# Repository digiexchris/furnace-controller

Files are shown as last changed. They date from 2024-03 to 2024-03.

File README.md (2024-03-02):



# furnace-controller
Simple 5 wire furnace controller using the Lotlin S2 Mini. Intended for ESPHome and Home Assistant or other automation uses.

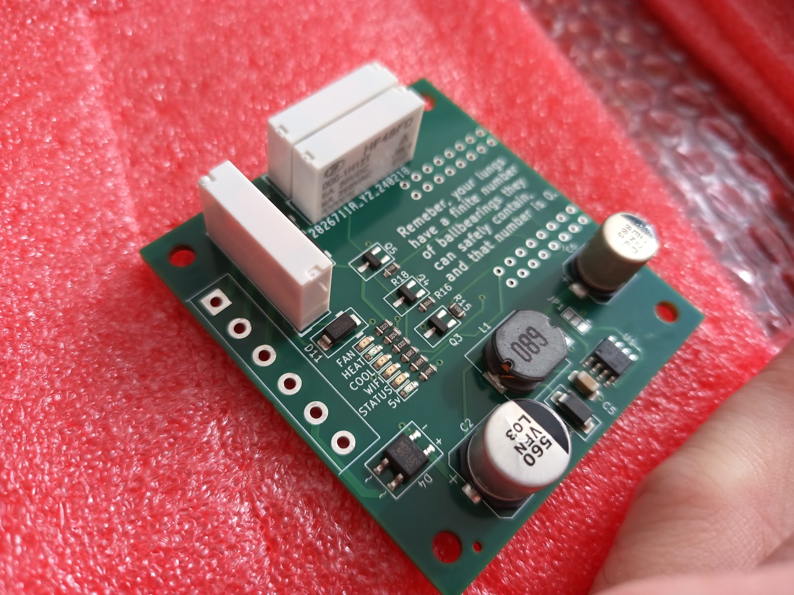
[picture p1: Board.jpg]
Board

Back
Running

# Why this exists
It's difficult to find a power supply to run an esp32 or esp8266 (or any 5vdc device for that matter) off of the 24vac transformer typically used in a furnace. This is intended to provide power and 3 relays connected to an esp8266 so that it can run anywhere that the thermostat wires are run in your house (or, as in my case, mounted directly to the furnace cabinet).

# Deets
- Accepts AC or DC input power, up to about 30V maximum. It's possible that it will accept up to 42v, but I have not tested it at that level, and you very likely will let the smoke out. Check the specs on the DC-DC IC for more info.
- 5A Relays, up to 30VDC or 250VAC contacts. 
- Avoids most of the multipurpose pins on the lotlin S2 mini, so you can use them for something else.
- Provides das blinken lighten for telling you if the furnace should be on

# Pinout

| Function | Esp32-S2 Pin |
|---|---|
| Heat | IO35 |
| Cool | IO18 |
| Fan | IO33 |
| WIFI Led | IO09 |
| Status LED | IO05 |

# I WANT ONE!

You have a few options:
- whack together one using whatever you have on hand using the schematic (see the kicad project, Kicad 8.0 btw.)
- Shoot me an email at chris@voiditswarranty.com, or see VoidItsWarranty.com, and ask me to make one for you
- Have a board house like jlcpcb make you one. The kicad folder contains the production files used for my first few.

# Example ESPHome config

See furnace-controller.yaml in the root of this project for an example ESPHome config. Once it's up and running in ESPHome, you can use it as a normal set of switches for your thermostat, or any other automation that the relays can support.

# FAQ
- Q: The LEDs are too bright! A: yup, sorry about that
- Q: Will it work on my furnace? A: no idea. Probably, if it's a standard 3-5 wire thermostat and the control circuitry is 24VAC.
- Q: I don't like it. A: Neither does my carpal tunnel.

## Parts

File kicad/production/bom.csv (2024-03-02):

Designator | Footprint | Quantity | Value | LCSC Part #
C2 | CP_Elec_10x10.5 | 1 | 470uf 35v
C5 | 1206 | 1 | 1uf 50v
C6 | CP_Elec_8x10.5 | 1 | 180uf 20v
D1 | 0603 | 1 | 5v | C2286
D10 | 0603 | 1 | COOL | C72038
D11, D12, D13, D15 | D_SMA | 4 | SS14 | C2480
D14 | 0603 | 1 | WIFI | C72038
D2 | 0603 | 1 | FAN | C72038
D3 | 0603 | 1 | HEAT | C2286
D4 | Diode_Bridge_MBS | 1 | MB10S | C2488
D5 | 0603 | 1 | STATUS | C72038
H1, H2, H3, H4 | MountingHole_3.5mm | 4 | MountingHole
J1 | TerminalBlock_bornier-6_P5.08mm | 1 | Screw_Terminal_01x06 | C5188023
JP1 | SolderJumper-3_P1.3mm_Bridged2Bar12_Pad1.0x1.5mm | 1 | Jumper_2_Bridged
JP2 | SolderJumper-2_P1.3mm_Bridged_Pad1.0x1.5mm | 1 | Jumper_2_Bridged
K1, K2, K5 | Relay_SPST_TE_PCN-1xxD3MHZ | 3 | UMS05-1A80-75L | C28975
L1 | L_10.4x10.4_H4.8 | 1 | 68uh 2a
Q3, Q4, Q5 | SOT-23_BigPads | 3 | MMBT3904 | C20526
R13 | 0603 | 1 | 2k | C17437
R14 | 0603 | 1 | 2k | C17408
R15, R16, R18 | 0603 | 3 | 470 | C17710
R17 | 0603 | 1 | 2k | C17471
R19, R21 | 0603 | 2 | 1k | C17720
R2k1 | 0603 | 1 | 1k | C17415
U1 | SOIC-8-1EP_3.9x4.9mm_P1.27mm_EP2.41x3.81mm | 1 | XL1509-5.0
U2 | ESP32_lotlin_mini | 1 | mini_esp32

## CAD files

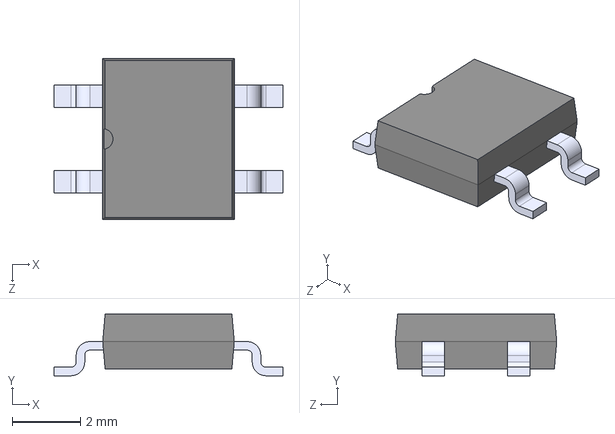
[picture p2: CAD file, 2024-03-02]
kicad/footprints/mb10f/MB10F-13.step
6.70 x 1.80 x 4.72 mm

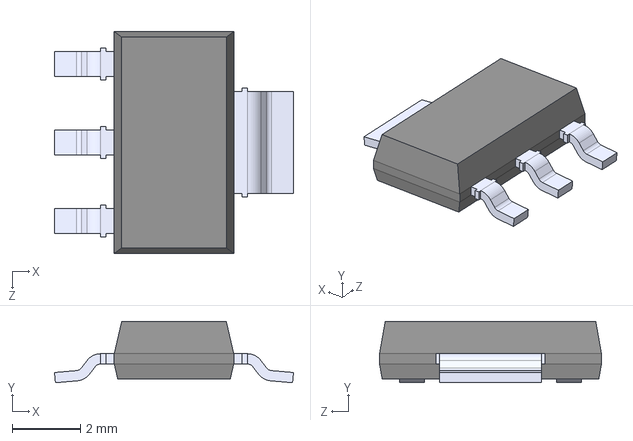
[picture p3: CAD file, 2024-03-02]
kicad/footprints/ncp1117/NCP1117STAT3.step
7.00 x 1.80 x 6.50 mm

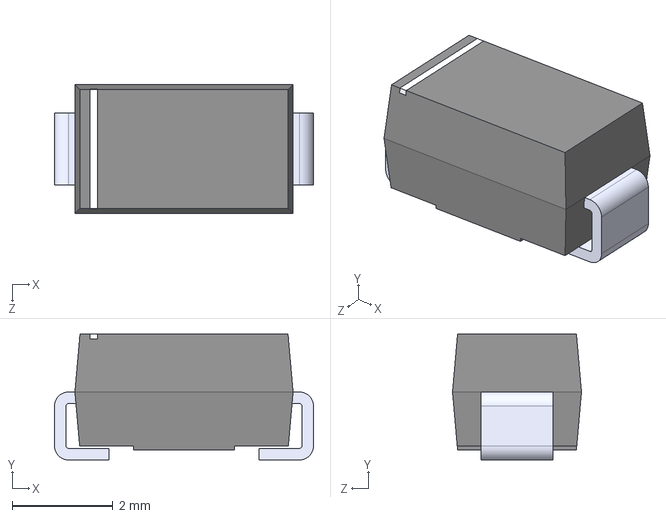
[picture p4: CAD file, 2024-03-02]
kicad/footprints/ss14/SS14.step
5.14 x 2.50 x 2.56 mm

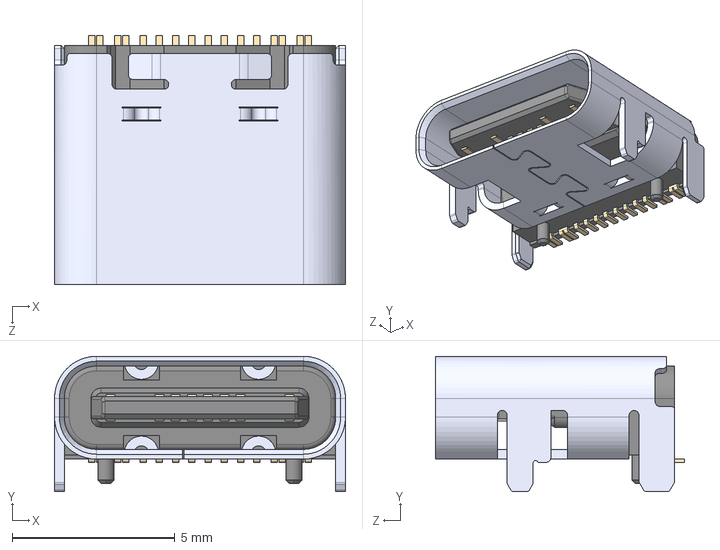
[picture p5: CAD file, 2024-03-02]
kicad/footprints/usb-c/TYPE-C_16PIN_2MD__073_.step
8.94 x 4.16 x 7.65 mm

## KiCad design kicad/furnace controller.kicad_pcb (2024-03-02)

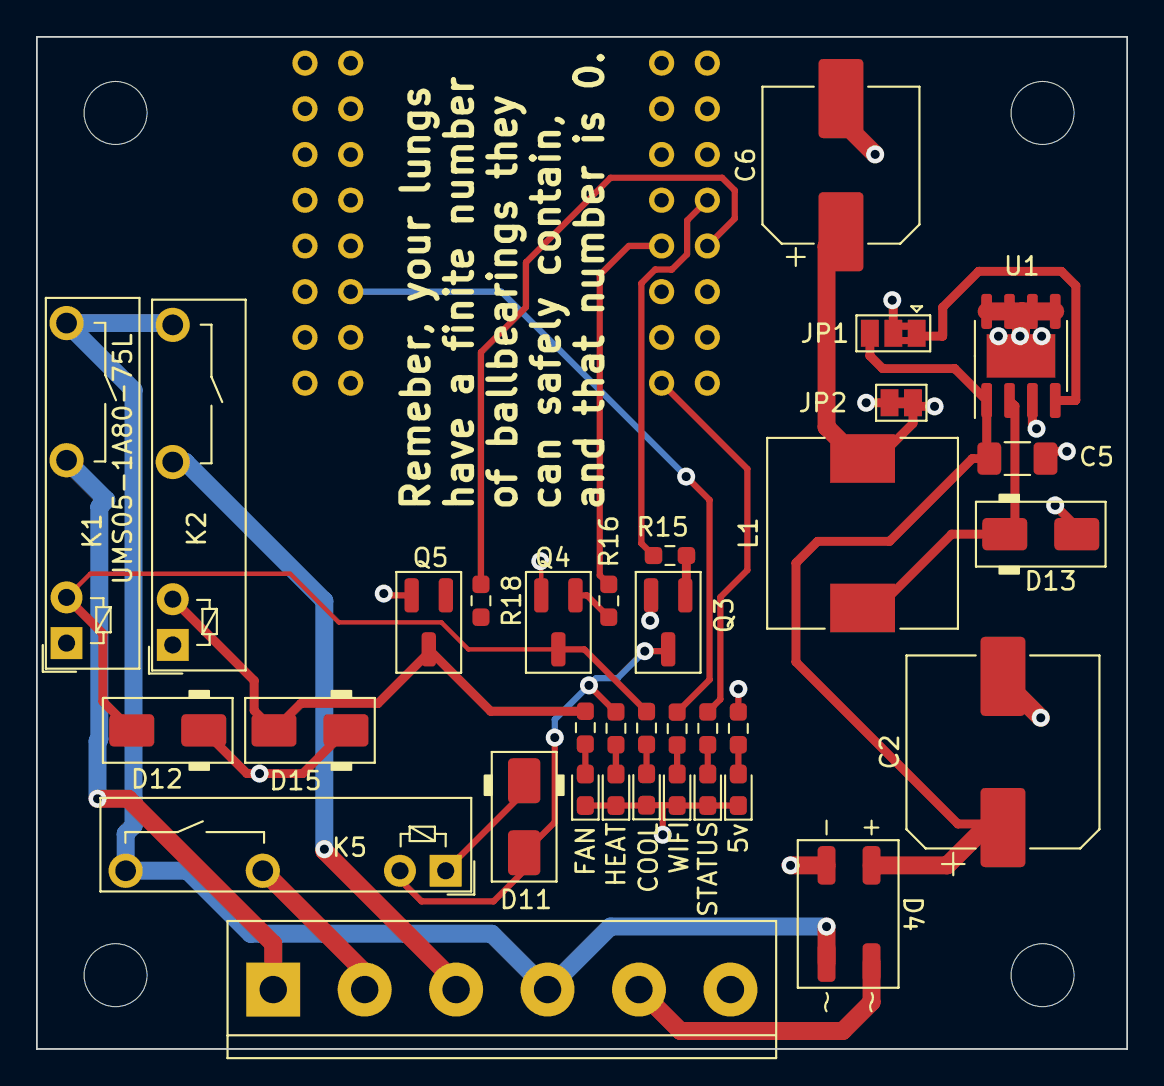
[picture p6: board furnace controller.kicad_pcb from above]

Board: 4 copper layers, 60.6 x 56.2 mm, 39 parts (1 on the bottom side), 28 nets.

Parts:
C2: 470uf 35v; CP_Elec_10x10.5
C5: 1uf 50v; C_1206_3216Metric_Pad1.33x1.80mm_HandSolder
C6: 180uf 20v; CP_Elec_8x10.5
D1: 5v; LED_0603_1608Metric_Pad1.05x0.95mm_HandSolder
D2: FAN; LED_0603_1608Metric_Pad1.05x0.95mm_HandSolder
D3: HEAT; LED_0603_1608Metric_Pad1.05x0.95mm_HandSolder
D4: MB10S; Diode_Bridge_MBS
D5: STATUS; LED_0603_1608Metric_Pad1.05x0.95mm_HandSolder
D10: COOL; LED_0603_1608Metric_Pad1.05x0.95mm_HandSolder
D11, D12, D13, D15: SS14; D_SMA
D14: WIFI; LED_0603_1608Metric_Pad1.05x0.95mm_HandSolder
H1, H2, H3, H4: MountingHole; MountingHole_3.5mm
J1: Screw_Terminal_01x06; TerminalBlock_bornier-6_P5.08mm
JP1: Jumper_2_Bridged; SolderJumper-3_P1.3mm_Bridged2Bar12_Pad1.0x1.5mm
JP2: Jumper_2_Bridged; SolderJumper-2_P1.3mm_Bridged_Pad1.0x1.5mm
K1, K2, K5: UMS05-1A80-75L; Relay_SPST_TE_PCN-1xxD3MHZ
L1: 68uh 2a; L_10.4x10.4_H4.8
Q3, Q4, Q5: MMBT3904; SOT-23_BigPads
R2k1, R19, R21: 1k; R_0603_1608Metric_Pad0.98x0.95mm_HandSolder
R13, R14, R17: 2k; R_0603_1608Metric_Pad0.98x0.95mm_HandSolder
R15, R16, R18: 470; R_0603_1608Metric_Pad0.98x0.95mm_HandSolder
U1: XL1509-5.0; SOIC-8-1EP_3.9x4.9mm_P1.27mm_EP2.41x3.81mm
U2: mini_esp32; ESP32_lotlin_mini

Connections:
+5V: D11.1 (K), D12.1 (K), D15.1 (K), JP2.2 (B), K1.1, K2.1, K5.1, R19.2, U2.35 (VCC_(USB)), U2.VBUS
/MCU/COOL: R16.1, U2.8 (IO_18/D5)
/MCU/FAN: R18.1, U2.9 (IO_33)
/MCU/HEAT: R15.1, U2.7 (IO_35)
/Power Supply/C: D4.4 (2), J1.5 (C)
/Relays/COOLLED: D12.2 (A), K1.2, Q4.3 (C), R14.2
/Relays/FANLED: D15.2 (A), K2.2, Q5.3 (C), R13.2
/Relays/G: J1.3 (G), K2.3
/Relays/HEATLED: D11.2 (A), K5.2, Q3.3 (C), R17.2
/Relays/W: J1.2 (W), K5.3
/Relays/Y: J1.1 (Y), K1.3
GND: C2.2, C5.2, C6.2, D1.1 (K), D2.1 (K), D3.1 (K), D4.2 (-), D5.1 (K), D10.1 (K), D13.2 (A), D14.1 (K), JP1.2 (C), Q3.2 (E), Q4.2 (E), Q5.2 (E), U1.5 (GND), U1.6 (GND), U1.7 (GND), U1.8 (GND), U1.9 (GND), U2.33 (GND), U2.GND
LINE: D4.3 (1), J1.4 (R), K1.4, K2.4, K5.4
unnamed: D1.2 (A), R19.1
unnamed: D2.2 (A), R13.1
unnamed: D3.2 (A), R17.1
unnamed: C2.1, C5.1, D4.1 (+), JP1.3 (B), U1.1 (VIN)
unnamed: D5.2 (A), R21.1
unnamed: D10.2 (A), R14.1
unnamed: D13.1 (K), L1.1, U1.2 (OUT)
unnamed: D14.2 (A), R2k1.1
unnamed: JP1.1 (A), U1.4 (~EN)
unnamed: C6.1, JP2.1 (A), L1.2, U1.3 (FB)
unnamed: Q3.1 (B), R15.2
unnamed: Q4.1 (B), R16.2
unnamed: Q5.1 (B), R18.2
unnamed: R21.2, U2.14 (IO_05/D8)
unnamed: R2k1.2, U2.17 (IO_09/SD2)

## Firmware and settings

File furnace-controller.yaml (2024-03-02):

esphome:
  name: furnace-controller

esp32:
  board: lolin_s2_mini

# Enable logging
logger:

switch:
  - platform: gpio
    pin: 8
    name: "Furnace Cool"
    id: relay1
    interlock: [relay2]
    restore_mode: RESTORE_DEFAULT_OFF

  - platform: gpio
    pin: 7
    name: "Furnace Heat"
    id: relay2
    interlock: [relay1]
    restore_mode: RESTORE_DEFAULT_OFF

  - platform: gpio
    pin: 9
    name: "Furnace Fan Only"
    id: relay3
    restore_mode: RESTORE_DEFAULT_OFF

output:
  - platform: gpio
    pin: 17
    id: WIFI_led
  - platform: gpio
    pin: 14
    id: status_led

interval:
  - interval: 1s
    then:
      if:
        condition:
          wifi.connected:
        then:
          - output.turn_on: WIFI_led
          - if:
              condition:
                api.connected:
              then:
                - output.turn_on: status_led
              else:
                - output.turn_off: status_led
        else:
          - output.turn_off: WIFI_led
          - output.turn_off: status_led

sensor:
  - platform: wifi_signal
    name: "Furnace WiFi Signal"
    update_interval: 10s

binary_sensor:
  - platform: status
    name: "Furnace Status"

# Enable Home Assistant API
api:
  encryption:
    key: "YOUR KEY NOT MINE"

ota:
  password: "YOUR PASSWORD NOT MINE, have ESPHome generate these for you"

wifi:
  ssid: !secret wifi_ssid
  password: !secret wifi_password

  # Enable fallback hotspot (captive portal) in case wifi connection fails
  #ap:
  #  ssid: "Furnace-Controller"
  #  password: "xN6h3JgsXoET"

#captive_portal:
    
